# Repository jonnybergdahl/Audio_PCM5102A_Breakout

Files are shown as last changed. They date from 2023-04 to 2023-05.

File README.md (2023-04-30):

# Audio_PCM5102A_Breakout

This is a breakout board for the Texas Instrument PCM5102A chip. It is a I2S Audio Stereo DAC.

According to the manufacturer:

>The PCM510xA devices are a family of monolithic
CMOS-integrated circuits that include a stereo digital-to-analog converter and additional support circuitry in
a small TSSOP package.

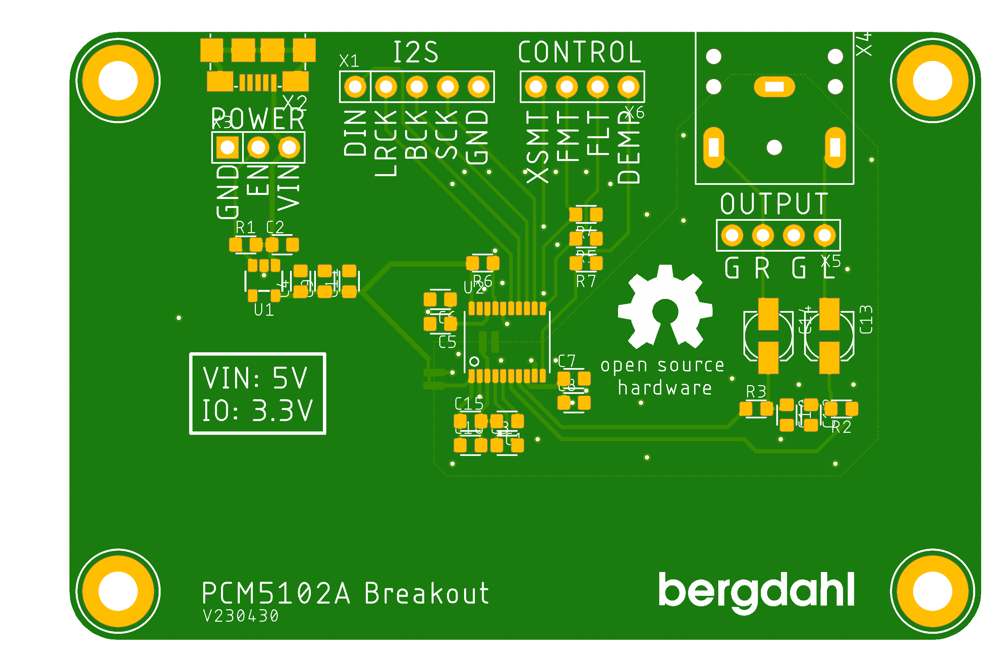
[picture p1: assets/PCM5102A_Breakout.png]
Image of PCB PCB


## I2S Pins

Name | Description
---- | ----
DIN | Audio iata in
LRCK | Audio data word clock input
BCK | Audio data bit clock input
SCK | System clock inout
GND | Digital ground

## Control pins
Name | Description
---- | ----
XSMT | Soft mute control
FMT | Audio format selection
FLT | Filter select
DEMP | De-amphasis control for 44.1-kHz sampling rate

## Power
Name | Description
---- | ----
VIN | 5V power, regulated sown to 3.3V with on board LDO
EN | Enable power, 1 = On, has pullup resistor on board
GND | Ground

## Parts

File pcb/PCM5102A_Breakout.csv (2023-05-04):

Qty | Value | Device | Package | Parts | Description
4 | 100nF | CAPC0603 | C0603 | C5, C7, C9, C15
4 | 10K | RESISTOR0603 | R0603 | R4, R5, R6, R7
2 | 10uF | CAP-POL-ALUMROQANG-RVT0405 | ROQANG-RVT0405 | C13, C14
4 | 10uF | CAPC0603 | C0603 | C6, C8, C11, C16
2 | 1uF | CAPC0603 | C0603 | C2, C4
2 | 2.2nF | CAPC0603 | C0603 | C10, C12
2 | 2.2uF | CAPC0603 | C0603 | C1, C3
2 | 470R | RESISTOR0603 | R0603 | R2, R3
1 | 47K | RESISTOR0603 | R0603 | R1
1 | AP2112K-3,3TRG1 | REGULATOR-AP2112KK-SOT23-5 | SOT23-5 | U1
1 | CONTROL | HEADER-1X04-2.54 | 1X04-2.54 | X6
1 | I2S | HEADER-1X05-2.54 | 1X05-2.54 | X1
1 | JACK | AUDIO-3.5-SJ1-3523N | AUDIO-3.5-SJ1-3523N | X4
4 | MOUNTHOLE-PAD3.2 | MOUNTHOLE-PAD3.2 | 3.2-PAD | H1, H2, H3, H4
1 | OUTPUT | HEADER-1X04-2.54 | 1X04-2.54 | X5
1 | PCM5102A | PCM5102APWR | TSSOP-20 | U2
1 | PWR | HEADER-1X03-2.54P | 1X03P-2.54 | X3
4 | SHORT-SMD-06096 | SHORT-SMD-06096 | SHORT-SMD-06096 | SH1, SH2, SH3, SH4
1 | USB-MICRO-B-FCI | USB-MICRO-B-FCI | USB-MICRO-B-FCI | X2 | FCI-10118192-0001LF

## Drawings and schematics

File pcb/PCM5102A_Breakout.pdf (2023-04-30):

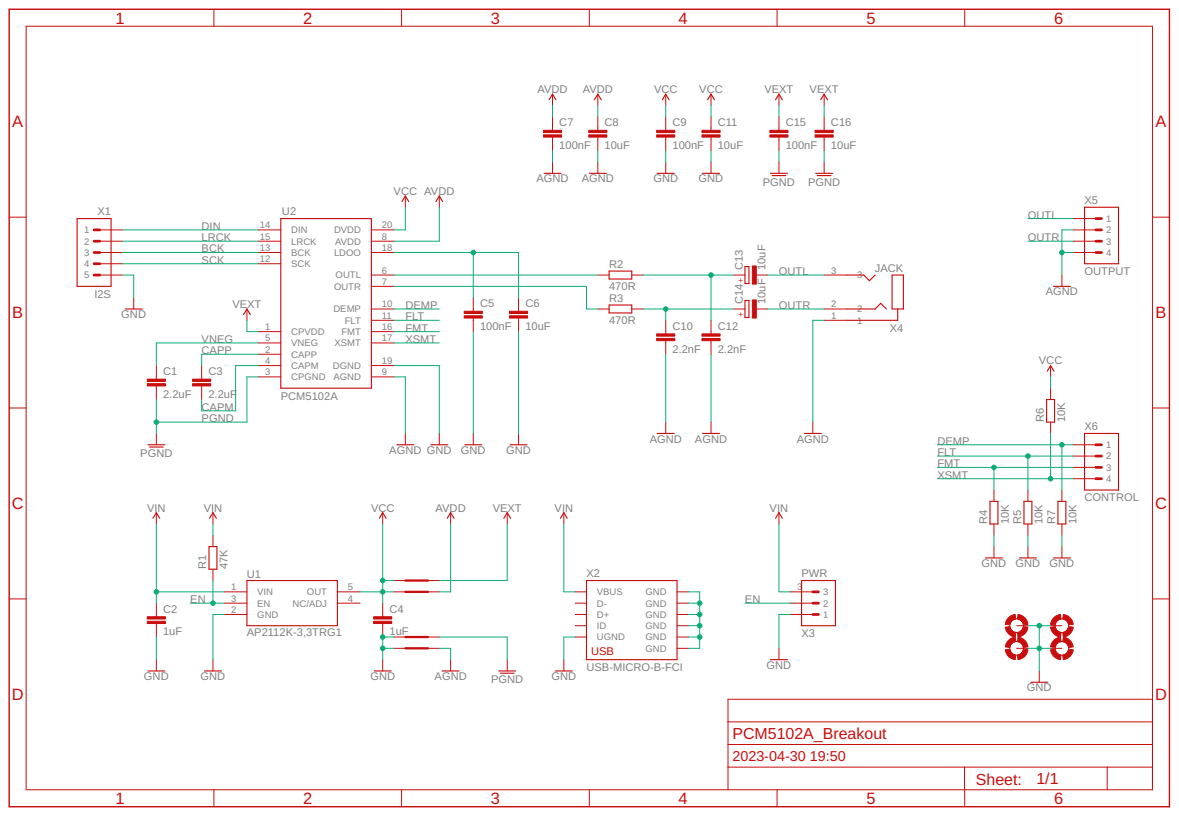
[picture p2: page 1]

6 OUTR

10 FLT DEMP

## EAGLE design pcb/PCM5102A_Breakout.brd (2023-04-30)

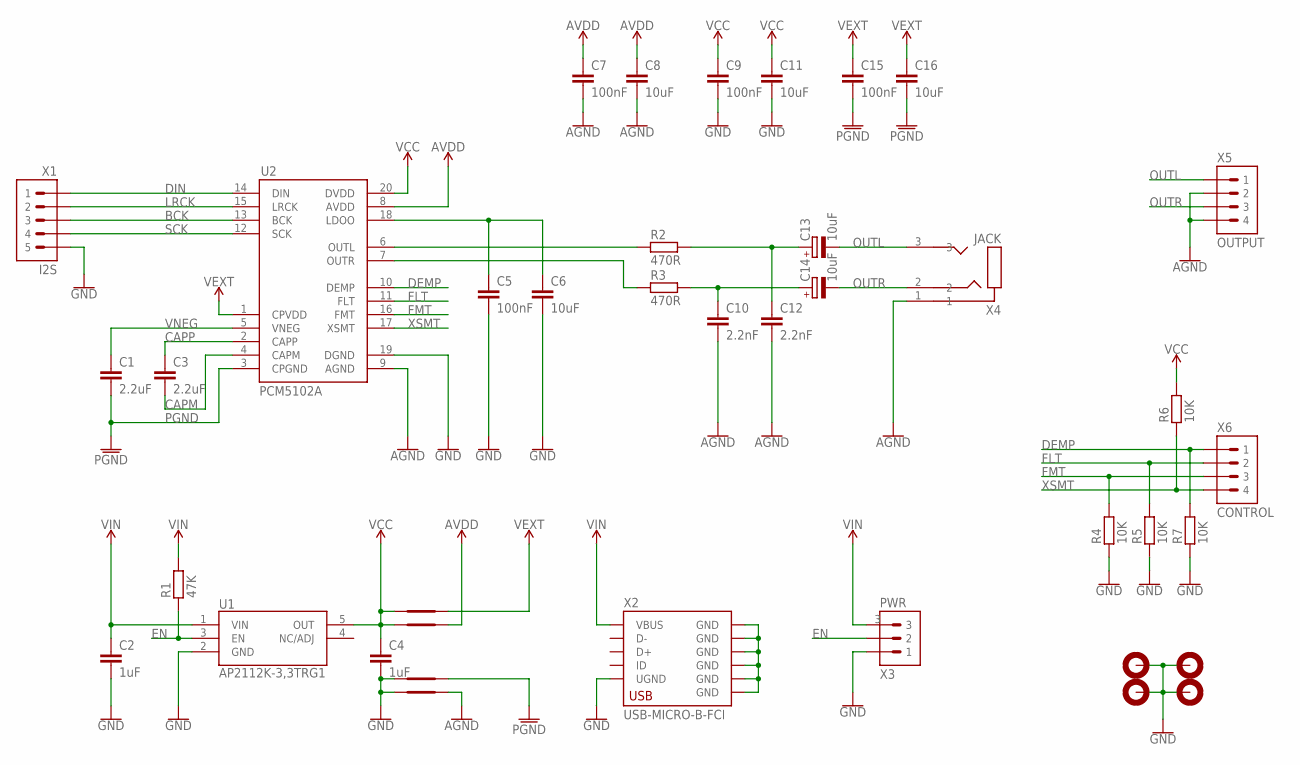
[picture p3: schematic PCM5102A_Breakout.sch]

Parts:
C1, C3: 2.2uF; C0603
C2, C4: 1uF; C0603
C5, C7, C9, C15: 100nF; C0603
C6, C8, C11, C16: 10uF; C0603
C10, C12: 2.2nF; C0603
C13, C14: 10uF; ROQANG-RVT0405
H1, H2, H3, H4: MOUNTHOLE-PAD3.2; 3.2-PAD
R1: 47K; R0603
R2, R3: 470R; R0603
R4, R5, R6, R7: 10K; R0603
SH1, SH2, SH3, SH4: SHORT-SMD-06096
U1: AP2112K-3,3TRG1; SOT23-5
U2: PCM5102A; TSSOP-20
X1: I2S; 1X05-2.54
X2: USB-MICRO-B-FCI
X3: PWR; 1X03P-2.54
X4: JACK; AUDIO-3.5-SJ1-3523N
X5: OUTPUT; 1X04-2.54
X6: CONTROL; 1X04-2.54

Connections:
AGND: C7.2, C8.2, C10.2, C12.2, SH4.2, U2.9 (AGND), X4.1, X5.2, X5.4
AVDD: C7.1, C8.1, SH2.2, U2.8 (AVDD)
BCK: U2.13 (BCK), X1.3
CAPM: C3.2, U2.4 (CAPM)
CAPP: C3.1, U2.2 (CAPP)
DEMP: R7.2, U2.10 (DEMP), X6.1
DIN: U2.14 (DIN), X1.1
EN: R1.1, U1.3 (EN), X3.2
FLT: R5.2, U2.11 (FLT), X6.2
FMT: R4.2, U2.16 (FMT), X6.3
GND: C2.2, C4.2, C5.2, C6.2, C9.2, C11.2, H1.B3,2, H2.B3,2, H3.B3,2, H4.B3,2, R4.1, R5.1, R7.1, SH3.1, SH4.1, U1.2 (GND), U2.19 (DGND), X1.5, X2.5 (UGND), X3.1
LRCK: U2.15 (LRCK), X1.2
unnamed: C5.1, C6.1, U2.18 (LDOO)
unnamed: R2.1, U2.6 (OUTL)
unnamed: R3.1, U2.7 (OUTR)
unnamed: C12.1, C13.+, R2.2
unnamed: C10.1, C14.+, R3.2
unnamed: X2.GND@1 (GND), X2.GND@2 (GND), X2.GND@3 (GND), X2.GND@4 (GND), X2.GND@5 (GND), X2.GND@6 (GND)
OUTL: C13.-, X4.3, X5.1
OUTR: C14.-, X4.2, X5.3
PGND: C1.2, C15.2, C16.2, SH3.2, U2.3 (CPGND)
SCK: U2.12 (SCK), X1.4
VCC: C4.1, C9.1, C11.1, R6.2, SH1.1, SH2.1, U1.5 (OUT), U2.20 (DVDD)
VEXT: C15.1, C16.1, SH1.2, U2.1 (CPVDD)
VIN: C2.1, R1.2, U1.1 (VIN), X2.1 (VBUS), X3.3
VNEG: C1.1, U2.5 (VNEG)
XSMT: R6.1, U2.17 (XSMT), X6.4

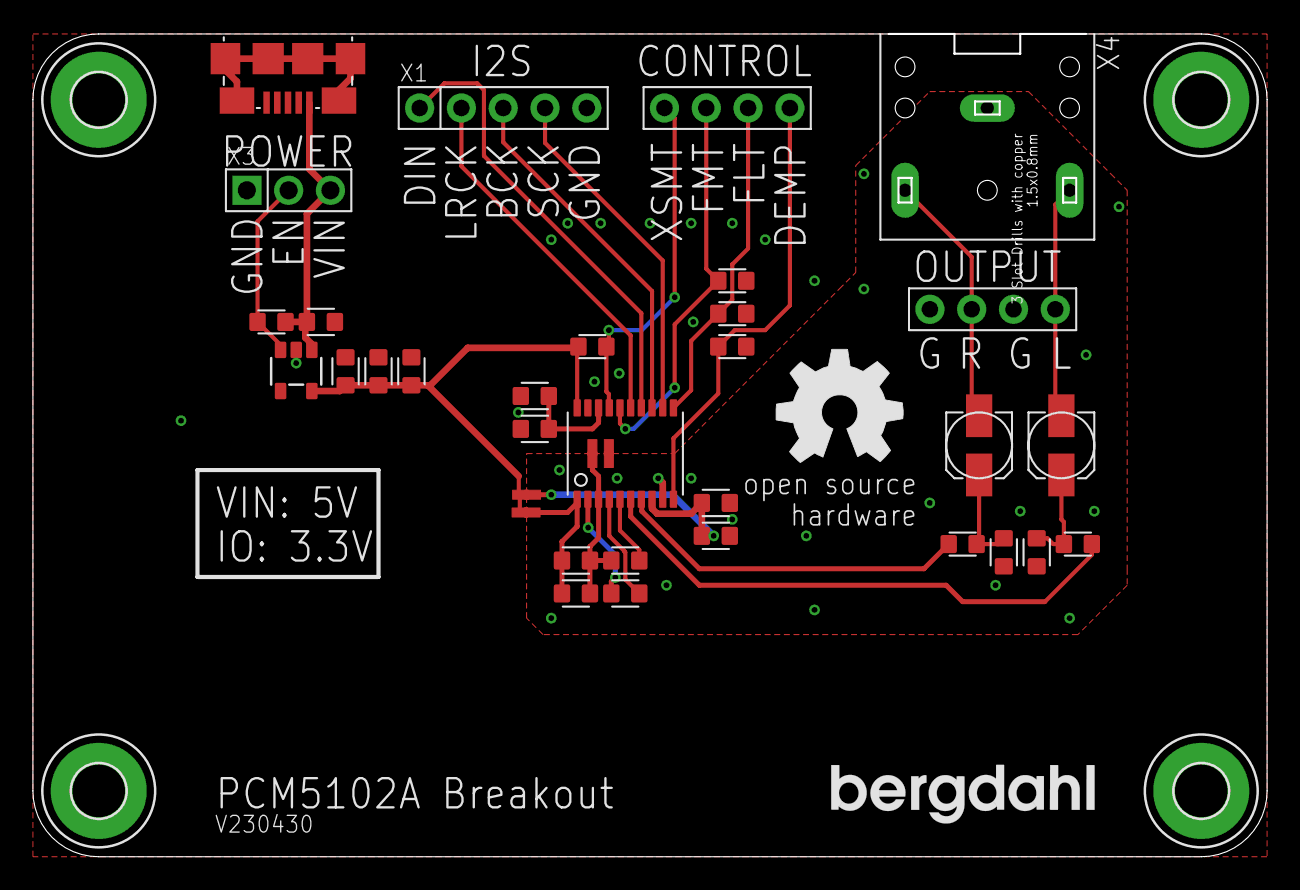
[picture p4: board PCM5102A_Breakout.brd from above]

Board: 2 copper layers, 75.0 x 50.0 mm, 41 parts (0 on the bottom side), 27 nets.

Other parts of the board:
U$1: BERGDAHL-20MM-TPLACE
U$2: OSHW-8MM-TPLACE
